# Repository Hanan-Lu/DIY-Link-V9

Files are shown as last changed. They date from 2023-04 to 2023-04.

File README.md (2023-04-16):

# DIY Link V9

此项目为一个Clone J-Link V9 的硬件项目，并进行了一些优化升级。

## 功能特点

    支持Jlink Base的全部功能，在此基础上增加一键切换内外参考电压功能，免去拆壳的繁琐

+ 支持电平转换，电压范围1.2~5V

+ 支持5V VOUT输出，输出采用MOS管控制，损耗更小

+ 优化电压跟踪器，真正的支持5V I/O电平，工作更稳定

+ 支持固件升级

+ 支持VCOM，(注意，开启VCOM后只能使用SWD模式)

+ 支持USB A to C及 C to C线

+ 用料扎实，布局合理，器件均为一线大厂(ST、Microchip、Nexperia、SG-Micro、Torex、Cvilux、JST/CJT、YXC、Yageo/Samsung 等)

+ PCB为无铅工艺

+ 接口线序采用ARM推荐的10Pin JTAG接口

+ 壳体采用CC-Debugger调试器外壳，可自行淘宝购买

## 实物图

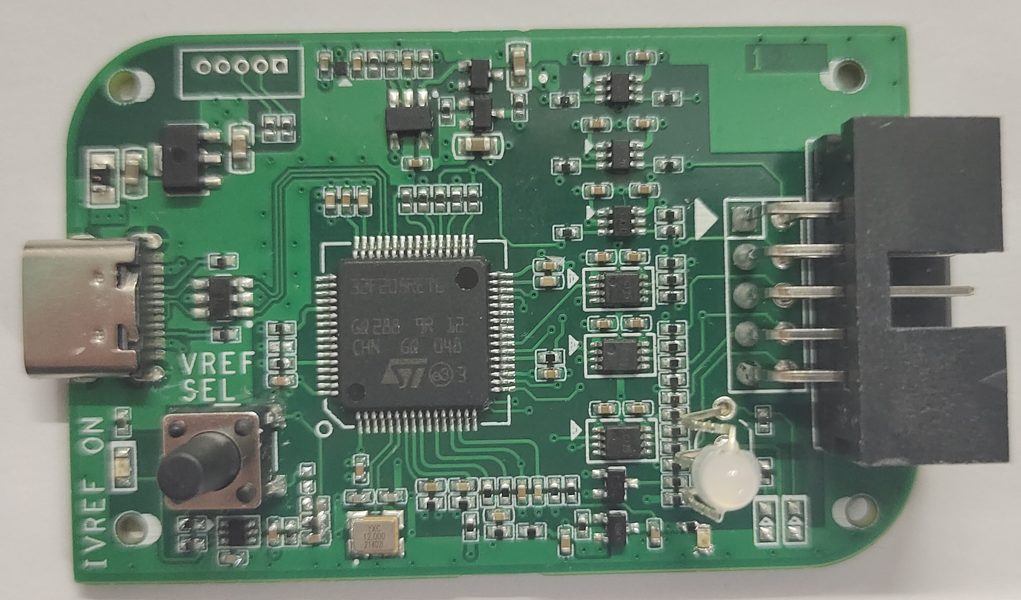
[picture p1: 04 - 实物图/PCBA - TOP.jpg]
"正面图" 正面图

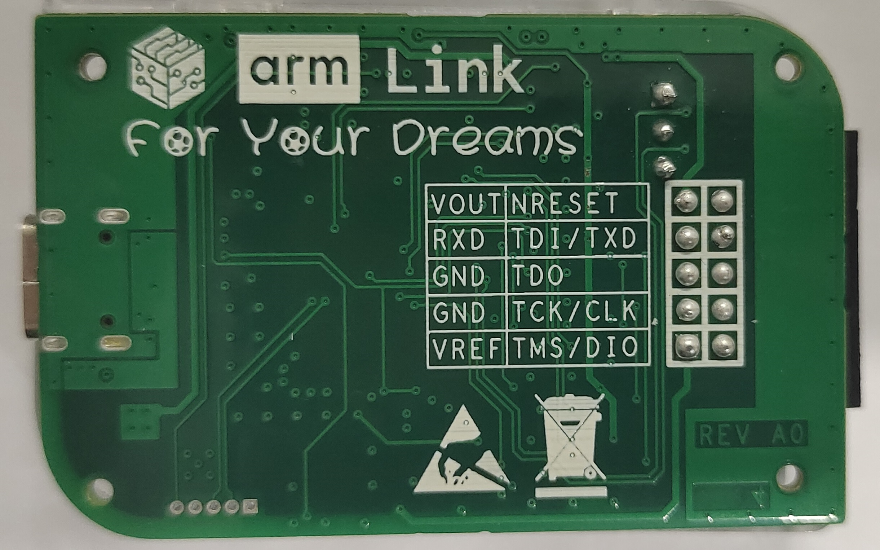
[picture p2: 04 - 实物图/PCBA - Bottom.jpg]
"背面图" 背面图

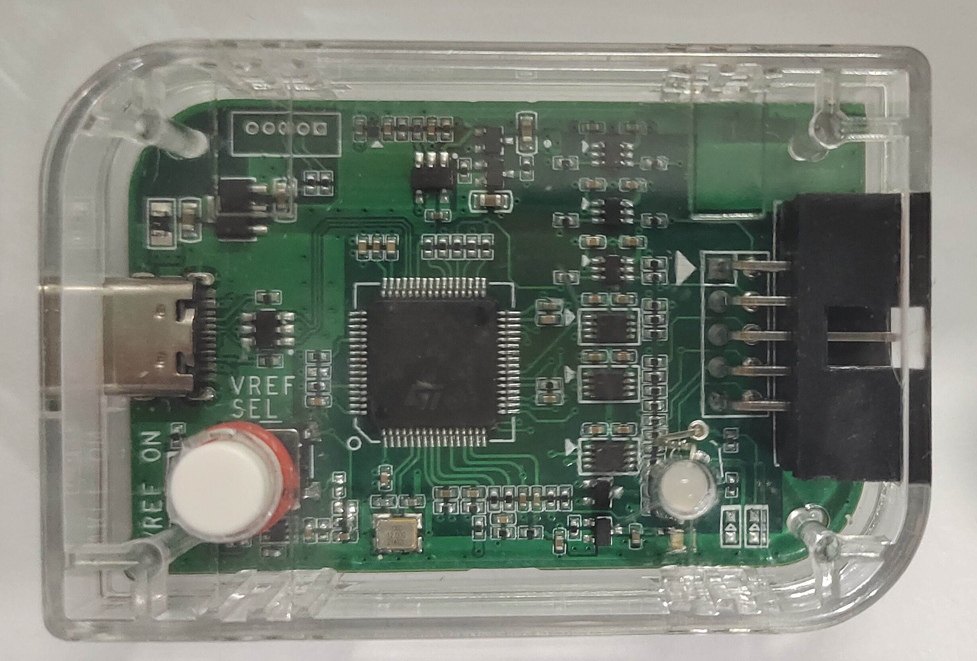
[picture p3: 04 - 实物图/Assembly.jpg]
"装配图" 装配图


## 注意事项

+ 开启内部参考电压后，VREF引脚上会输出一个3.3V电压，但是此电压不能带大负载，因为其内阻较大(默认为5.1±1% Ohm, 目的为保护作用)，因此如希望使用调试器供电建议使用VOUT引脚(5V输出)

+ 总电流消耗建议小于500mA ( 输入自恢复保险丝规格为0.5A/6V/0805 )

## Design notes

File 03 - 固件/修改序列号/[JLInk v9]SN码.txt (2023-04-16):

exec setsn=50121742
exec setsn=29159380

Exec AddFeature GDB      ;添加GDB 
Exec AddFeature RDI      ;添加RDI 
Exec AddFeature FlashBP  ;添加FlashBP  
Exec AddFeature FlashDL  ;添加FlashDL 
Exec AddFeature JFlash   ;添加JFlash 
Exec AddFeature RDDI     ;添加RDDI			//慎重，会报clone

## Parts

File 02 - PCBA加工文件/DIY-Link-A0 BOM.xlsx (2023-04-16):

序号 | 编码 | 描述 | 规格/型号 | 封装 | 用量 | 位号
1 | 01.02.000503 | GP MLCC, 10pF, 50Vdc, ±2%, C0G, EIA 0402 | 10pF/50V | 0402 | 3 | C1,C2,C38
2 | 01.02.000270 | GP MLCC, 4.7uF, 16, ±20%,V X5R, EIA 0402 | 4.7uF/16V | 0402 | 3 | C3,C4,C5
3 | 01.02.000072 | GP MLCC, 100nF, 50V, 10%, X7R, EIA 0402 | 100nF/50V | 0402 | 23 | C6,C7,C8,C9,C10,C11,C12,C13,C14,C15,C16,C17,C18,C19,C20,C21,C22,C23,C24,C28,C30,C33,C36
4 | 01.02.000032 | GP MLCC, 10nF, 16V, 10%, X7R, EIA 0402 | 10nF/16V | 0402 | 3 | C25,C26,C27
5 | 01.02.000331 | GP MLCC, 10uF, 16V ±10%, X5R, EIA 0603 | 10uF/16V | 0603 | 4 | C29,C31,C32,C41
6 | 01.02.000288 | GP MLCC, 1uF, 16V, ±10% X5R, EIA 0402 | 1uF/16V | 0402 | 5 | C34,C35,C39,C40
7 | 01.15.000104 | ESD Protection Diode, Very low capacitance, USBLC6-2SC6, IEC 61000-4-2 level 4, 3.5pF, SOT23-6 | USBLC6-2SC6 | SOT23-6L | 1 | D1
8 | 01.06.000003 | LED, Top, Clear, Red, 631nm, VF=2V, EIA 0603, Height=0.8mm | Red | 0603 | 2 | D4,LED1
9 | 01.15.000115 | PolySwitch Resettable PPTC, Ihold=0.50A, Itrip=1.00A, Vmax=6V, Imax=100A, Pd=0.5W, EIA0805 | 0.50A/6V | 0805 | 1 | F1
10 | 01.12.000361 | USB Type C Connector, CU3216SASDLR010-NH, USB 2.0, 5.0A, 7.35X8.94X3.31mm, 16Pin | CU3216SASDLR010-NH | Type-C-16P | 1 | J1
11 | 01.12.000648 | IDC Connector, Box Header, Right-Angle, 2.54mm, 2x5P | X9555WR-2x05-6TV01 | 2P54-2x5 | 1 | J2
12 | 01.12.000048 | Single Row THT Wafer Connector, 5Pin, 1.25mm, Vertical, 1.0A, 125V, 20mΩ | A1251WV-5P | con_1d25v_5p | 1 | J3
13 | 01.06.000002 | LED, Top, Clear, Green, 571nm, VF=2V, EIA 0603, Height=0.8mm | Green | 0603 | 1 | LED2
14 | 01.06.000079 | Bi-Color Indicator Lamp, XL-B324SURSYGW, Red+Green, Common Anode, Lens: White Diffused, VF: 1.9-2.3/3.0-3.4V, IF=40mA, IV: 180-200/300-400mcd, 620-625/588-590nm, F3 | XL-B324SURSYGW | F3 | 1 | LED3
15 | 01.07.000501 | Digital NPN Transistors(Resistor-Equipped), PDTC143ZU, R1: 4.7k, R2:47k, VCEO: 50V, IO: 100mA, PD: 200mW, SOT323 | PDTC143ZU | SOT323 | 2 | Q1,Q3
16 | 01.08.000344 | Single P Channel MOSFET, AO7401, VDS: -30V, VGS(th): -1.4V, ID: -1.4A, SOT-323 | AO7401 | SOT-323 | 2 | Q2,Q4
17 | 01.08.000339 | Small Signal Mosfet, N+P, NX3008CBKV, VDS: ±30V, VGS(th): ±1.1V, ID: 0.4/-0.22A, SOT-666 | NX3008CBKV | SOT-666 | 1 | Q5
18 | 01.01.005199 | THICK FILM CHIP RESISTORS, 22R, 1%, 1/16W, EIA 0402 | 22R/1% | 0402 | 8 | R1,R2,R3,R4,R5,R6,R7,R8
19 | 01.01.001640 | THICK FILM CHIP RESISTORS, 10k, 1%, 1/16W, EIA 0402 | 10K/1% | 0402 | 16 | R9,R10,R11,R33,R38,R39,R40,R41,R42,R43,R44,R45,R46,R49,R50,R53
20 | 01.01.005244 | THICK FILM CHIP RESISTORS, 5.1k, 1%, 1/16W, EIA 0402 | 5.1k/1% | 0402 | 3 | R12,R13,R48
21 | 01.01.001448 | THICK FILM CHIP RESISTORS, 100R, 1%, 1/16W, EIA 0402 | 100R/1% | 0402 | 5 | R14,R20,R21,R22,R35
22 | 01.01.005225 | THICK FILM CHIP RESISTORS, 470R, 1%, 1/16W, EIA 0402 | 470R/1% | 0402 | 11 | R15,R16,R17,R18,R19,R23,R24,R25,R34,R36,R57
23 | 01.01.005271 | THICK FILM CHIP RESISTORS, 220k, 1%, 1/16W, EIA 0402 | 220k/1% | 0402 | 7 | R26,R27,R28,R29,R30,R31,R32
24 | 01.01.005208 | THICK FILM CHIP RESISTORS, 51R, 1%, 1/16W, EIA 0402 | 51R/1% | 0402 | 1 | R37
25 | 01.01.001352 | THICK FILM CHIP RESISTORS, 10R, 1%, 1/16W, EIA 0402 | 10R/1% | 0402 | 2 | R47,R56
26 | 01.01.001544 | THICK FILM CHIP RESISTORS, 1.0k, 1%, 1/16W, EIA 0402 | 1.00k/1% | 0402 | 2 | R51,R52
27 | 01.01.005261 | THICK FILM CHIP RESISTORS, 47k, 1%, 1/16W, EIA 0402 | 47k/1% | 0402 | 1 | R54
28 | 01.13.000120 | SMD Tact Switch, Top Push, TL3301DF100RJ, 50mA@12VDC, Travel: 0.25mm, 100gf, 6x6x13mm | TL3301DF100RJ | 6x6x13mm | 1 | SW1
29 | 01.10.000378 | STM32F205RET6, Arm Cortex-M3 MCU with 512k ROM + 128k RAM, 120 MHz CPU , ART Accelerator, 1.8~3.6V, -40~85°C, LQFP-64 | STM32F205RET6 | LQFP-64 | 1 | U1
30 | 01.10.000600 | 2-Bit Dual-Supply Bus Transceiver With Configurable Level Shifting, AiP74LVC2T45YA8, VCCA:1.2~5.5V, VCCB:1.2~5.5V, MAX:420Mbps, VSSOP-8 | AiP74LVC2T45YA8 | VSSOP-8 | 3 | U2,U3,U4
31 | 01.10.000597 | Single-Bit Dual-Supply Bus Transceiver With Configurable Level Shifting, AiP74LVC1T45GB363, VCCA:1.2~5.5V, VCCB:1.2~5.5V, MAX:420Mbps, SOT363 | AiP74LVC1T45GC363 | SOT363 | 3 | U5,U6,U7
32 | 01.10.000607 | Single, GP-OpAmp, RRIO, 1.8~6.0V, GBW: 1MHz, MCP6001T-E/OT, -40~125°C, SOT-23-5 | MCP6001T-E/OT | SOT-23-5 | 1 | U8
33 | 01.09.000356 | Large Current Positive Voltage Regulators, 2%, No-Current Limited, XC6203E332PR-G, VO: 3.3V, IO: 400mA, PD: 500mW, SOT89-3 | XC6203E332PR-G | SOT89-3 | 1 | U9
34 | 01.09.000337 | Power Distribution Switch, With Reverse Current Protection, SGM2574A, 1~5.5V, 1A, WLCSP-0.8x0.8-4B | SGM2574A | WLCSP-0.8x0.8-4B | 1 | U10
35 | 01.11.000006 | SMDCrystal, 12MHz, 20pF, 10ppm, ESR=80Ohm, 3.2x2.5x0.6, 3225-4P | 12MHz | 3225-4P | 1 | Y1

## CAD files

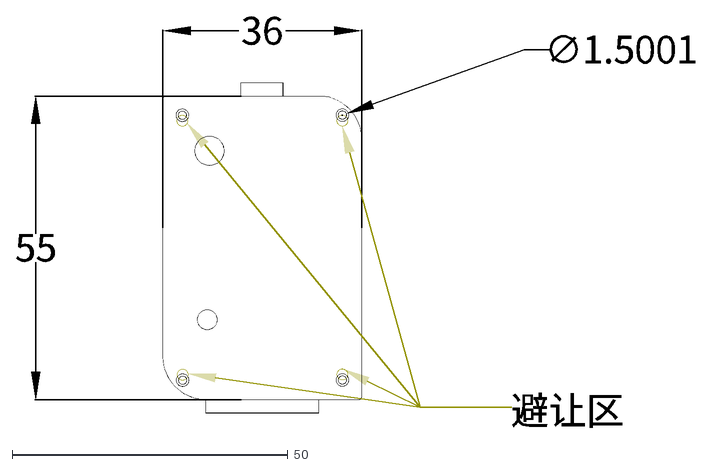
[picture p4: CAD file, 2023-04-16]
Outline.dxf
55
36
∅1.5001
避让区

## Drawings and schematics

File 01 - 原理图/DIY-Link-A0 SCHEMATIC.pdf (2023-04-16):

USB Type-C | STM32F205Rx Core

# MCU SWD Port

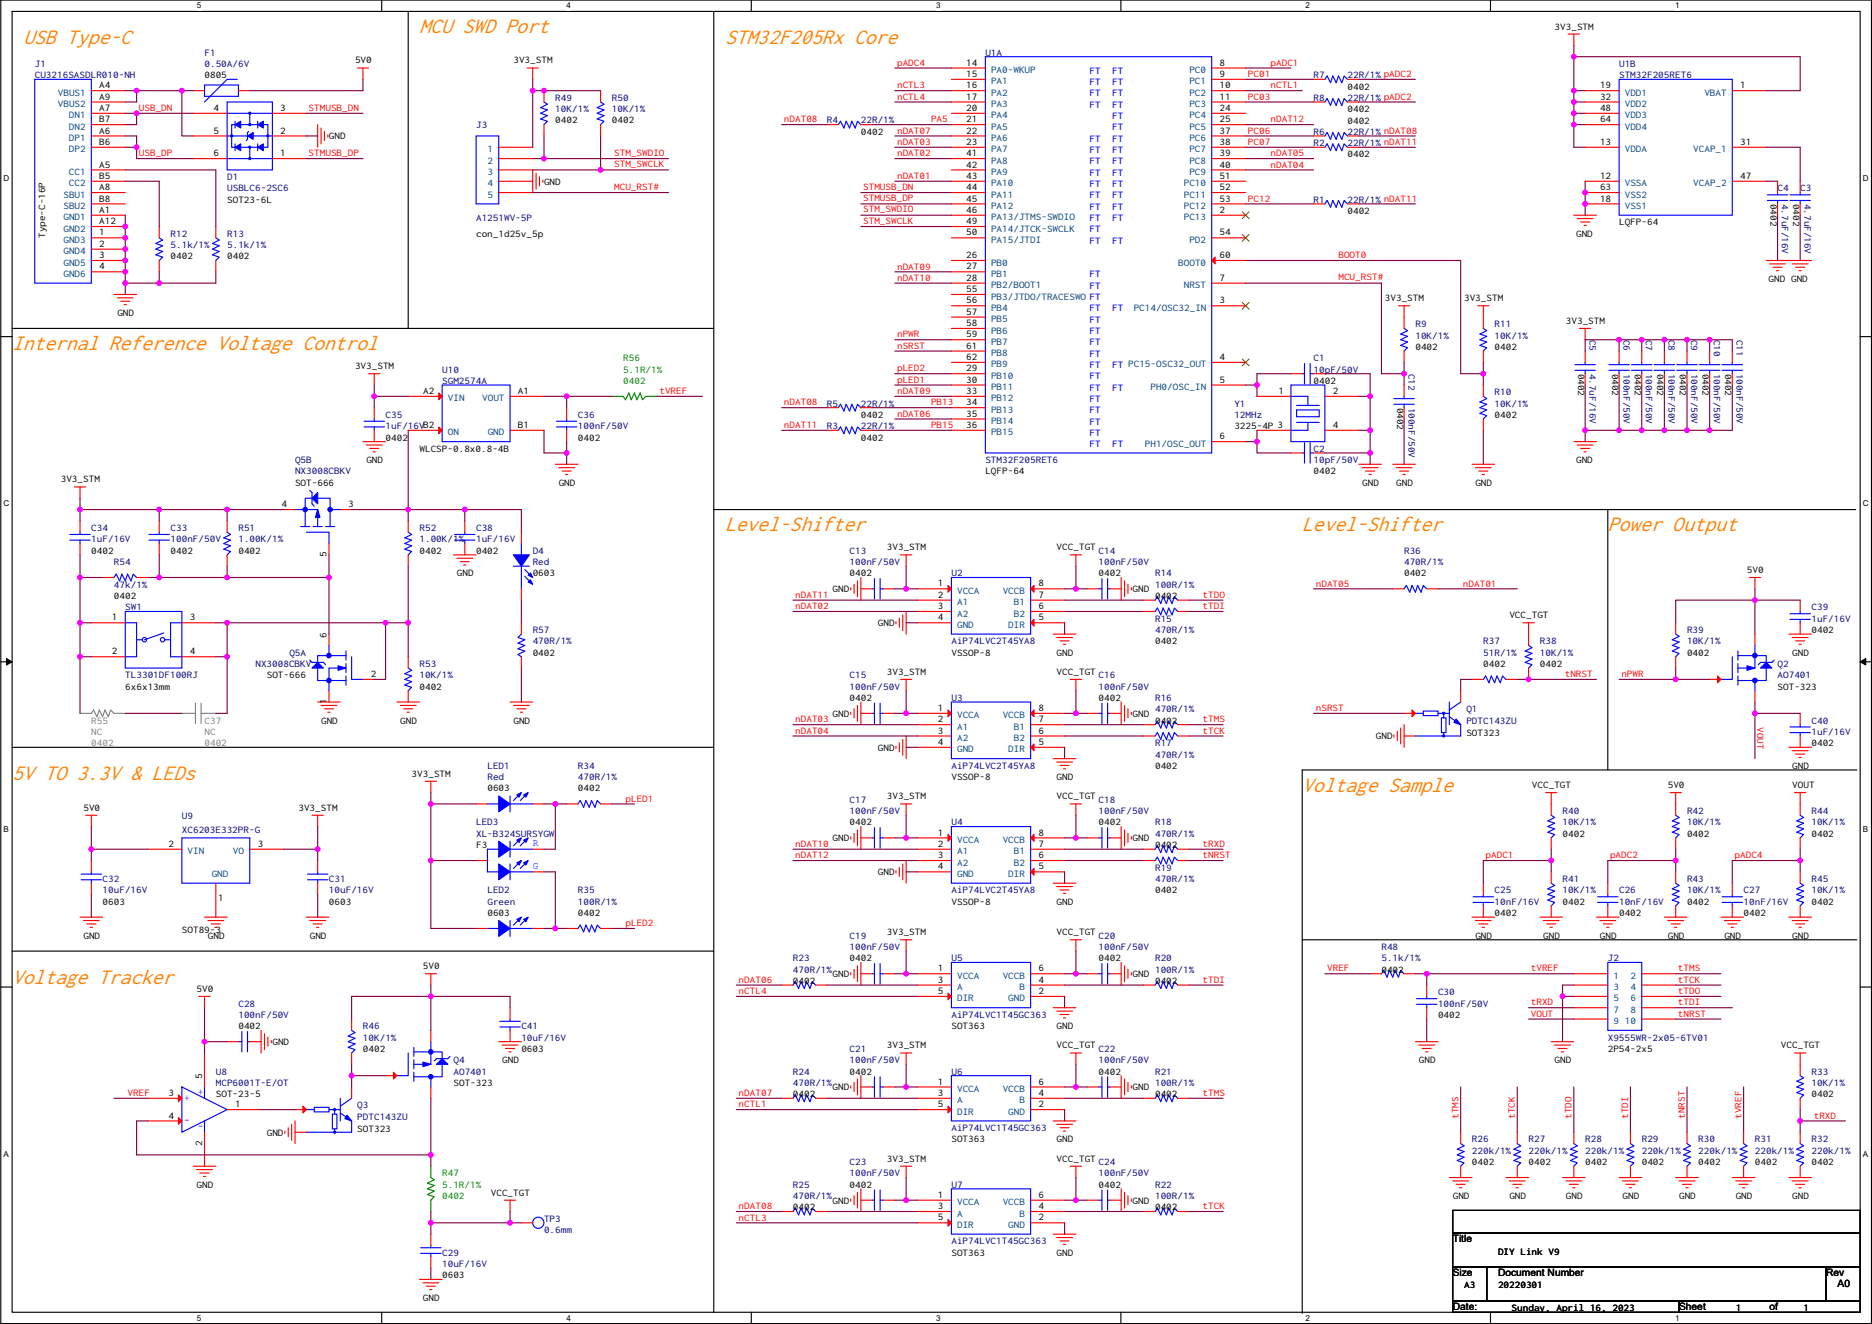
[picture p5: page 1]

Internal Reference Voltage Control

Size Size Size A3 A3 A3 | Document Number Document Number Document Number 20220301 20220301 20220301 | Rev Rev Rev A0 A0 A0

Date: Date: Date: Sunday, April 16, 2023 Sunday, April 16, 2023 Sunday, April 16, 2023 | Sheet Sheet Sheet 1 1 1 of of of 1 1 1

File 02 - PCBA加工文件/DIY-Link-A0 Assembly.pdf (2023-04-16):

# ART FILM - ASSEM_TOP

F1

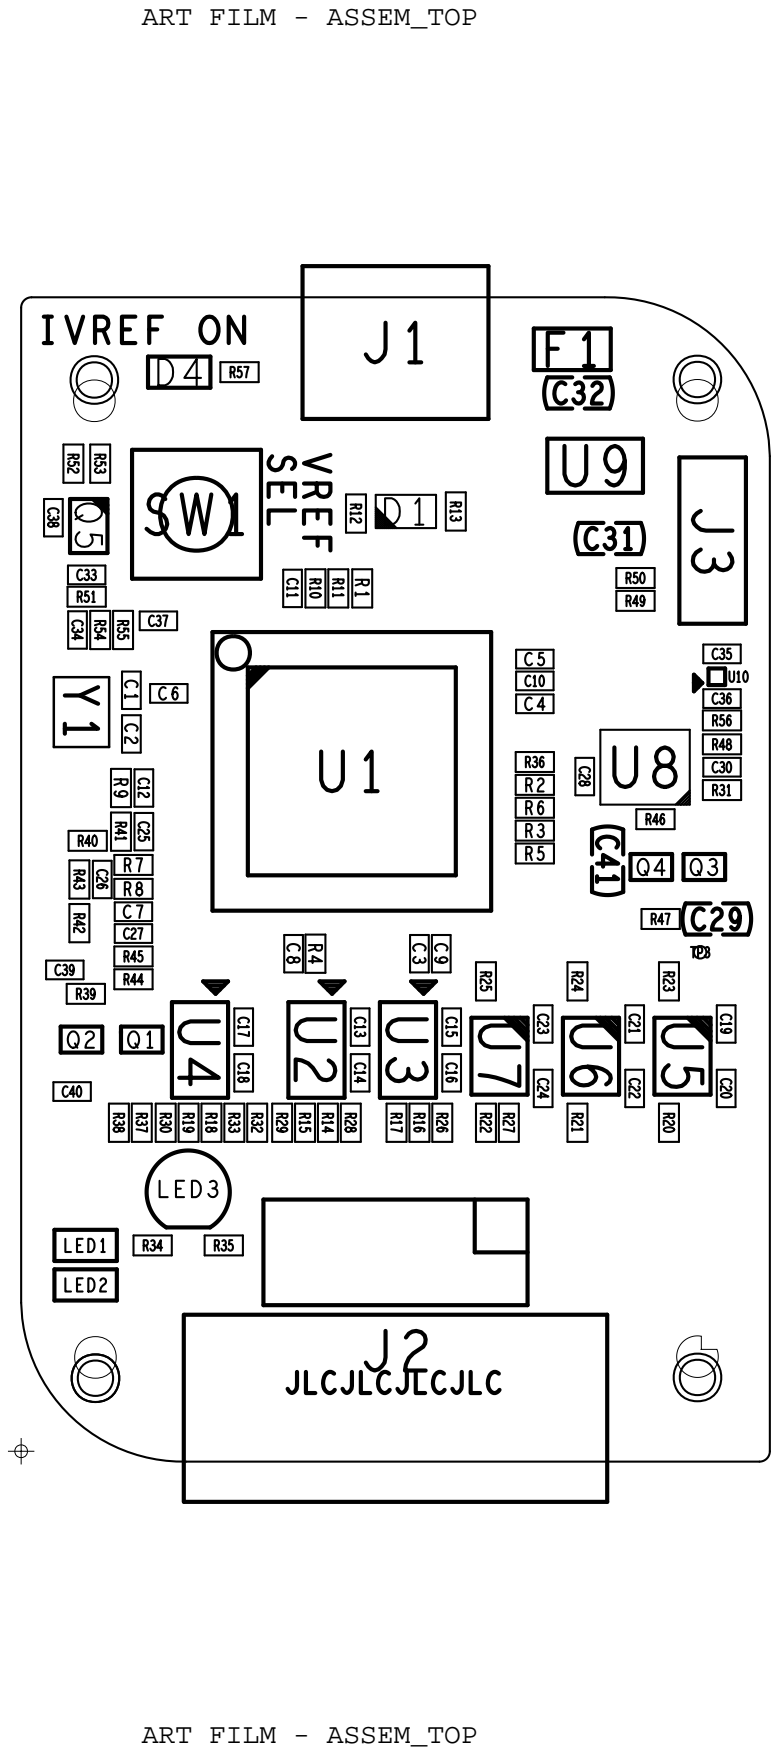
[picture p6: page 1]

LED1 | R34 R35

# ART FILM - ASSEM_BOTTOM

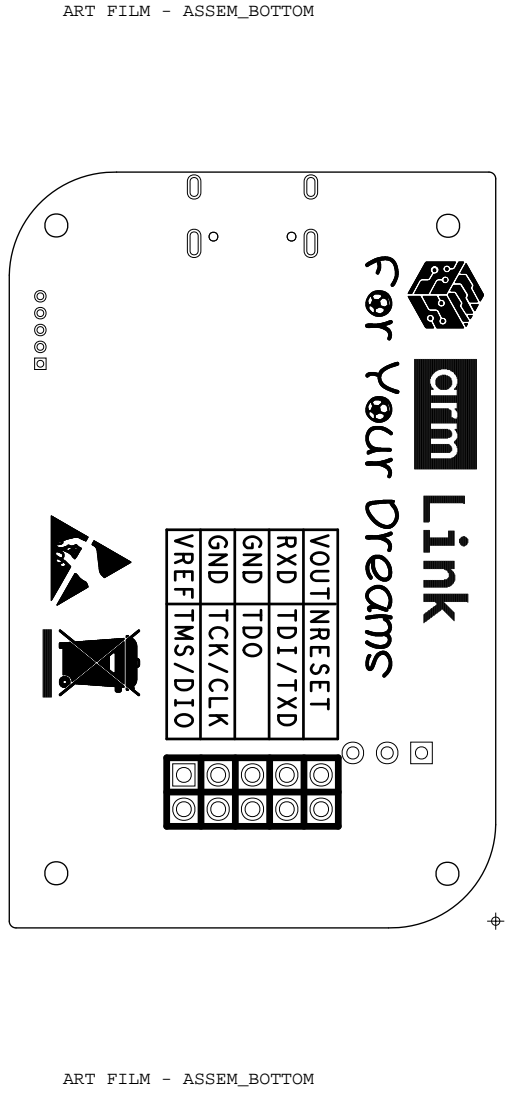
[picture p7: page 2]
ART FILM - ASSEM_BOTTOM VREF TMS/DIO; GND TCK/CLK; GND TDO; RXD; VOUT TDI/TXD; NRESET

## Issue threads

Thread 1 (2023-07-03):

功能描述

XL370, 2023-07-03:
支持SPI的采样和仿真模拟吗？

Hanan-Lu, 2023-07-04:
不支持，J-Link V9版本仅支持使用J-Flash SPI来烧录SPI Flash(例如W25Qxx), 采样和仿真模拟建议使用逻辑分析仪及数字信号发生器(例如稚晖君的[UltraLink](https://www.bilibili.com/video/BV1o24y187Gc/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))

Closed 2023-07-04.

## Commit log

2023-04-16 First Commit
    First Commit
    [DIY-Link-A0 BOM.xlsx]
2023-04-16 上传板框dxf文件
    上传板框dxf文件
    [Outline.dxf]
